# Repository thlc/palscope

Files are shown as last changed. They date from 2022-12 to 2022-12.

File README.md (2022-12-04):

PalScope -- PAL to X-Y-Z Oscilloscope Raster
============================================

About
-----

PalScope is a KiCad version of the very nice schematic made by
[W2AEW](https://www.qsl.net/w2aew/), which converts a PAL signal into 
a 3-channel X-Y-Z raster that oscilloscopes can use to display a raster image.

Components
----------

The board is based around an LM1881 IC that extracts vertical and horizontal
sync pulses from the PAL signal. Those pulses are used to drive capacitors
that produce a 0-9V signal for the X and Y channels.

The Z channel is used to dim parts of the screen using an inverting opamp.
While W2AEW used an AD8032, I had to use an AD844 because I couldn't find
the 8032. This opamp isn't the best, especially since it's current-based.
If you can get hold of a 8032, go this way!

Pictures
--------

Schematic:

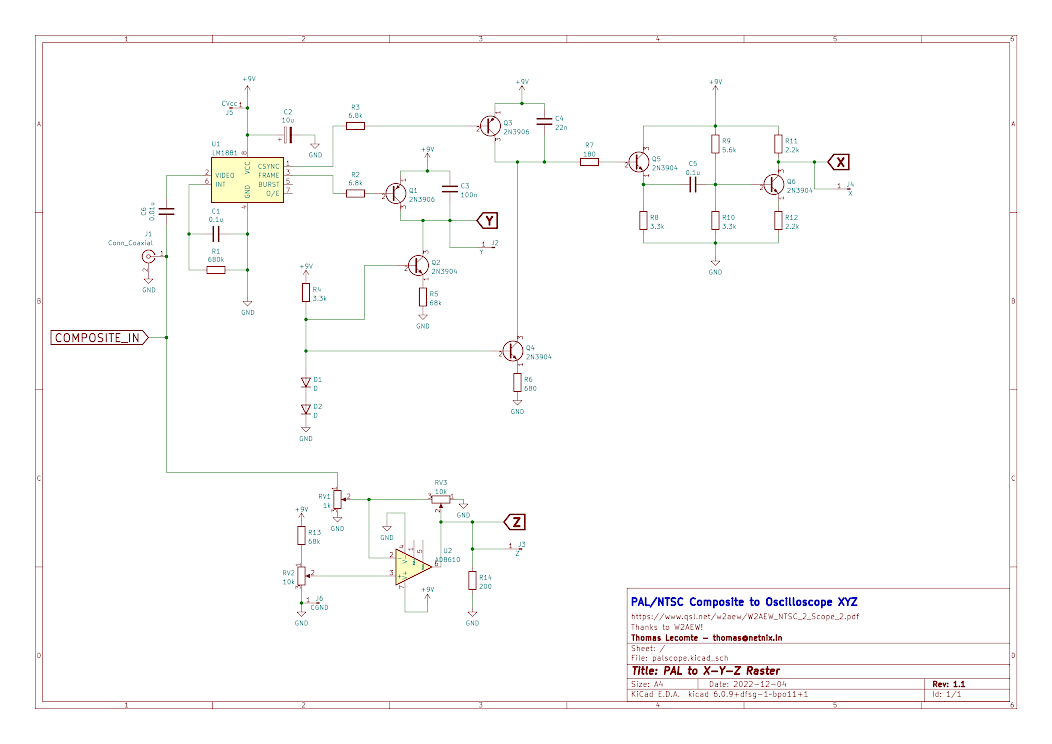
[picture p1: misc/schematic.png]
The Schematic


3-D rendering of the board:

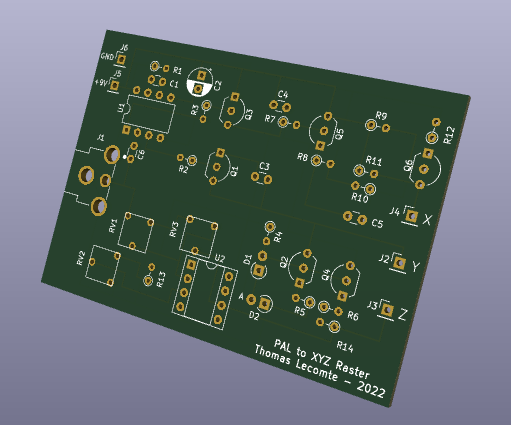
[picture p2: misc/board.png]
3-D Rendering


An early working version of the PCB:

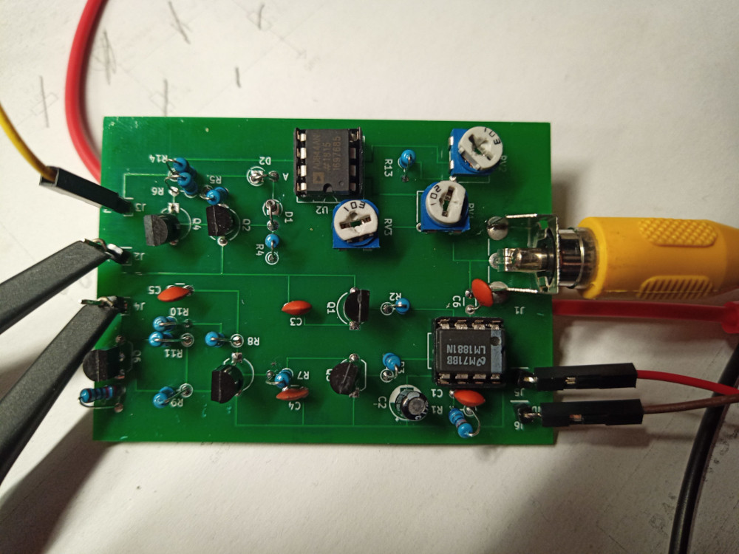
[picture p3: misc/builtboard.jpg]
PCB


My Apple //e running Ultima IV:

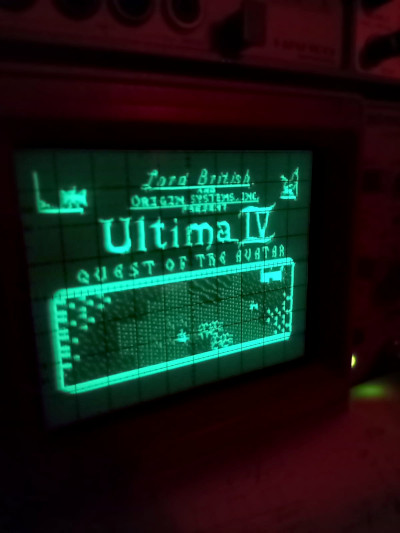
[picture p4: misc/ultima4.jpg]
Apple 2 running Ultima IV


Acknolwedgements
----------------

Thanks to Alan Wolke / W2AEW for publishing this design!
Make sure to check out his YouTube channel at https://www.youtube.com/@w2aew

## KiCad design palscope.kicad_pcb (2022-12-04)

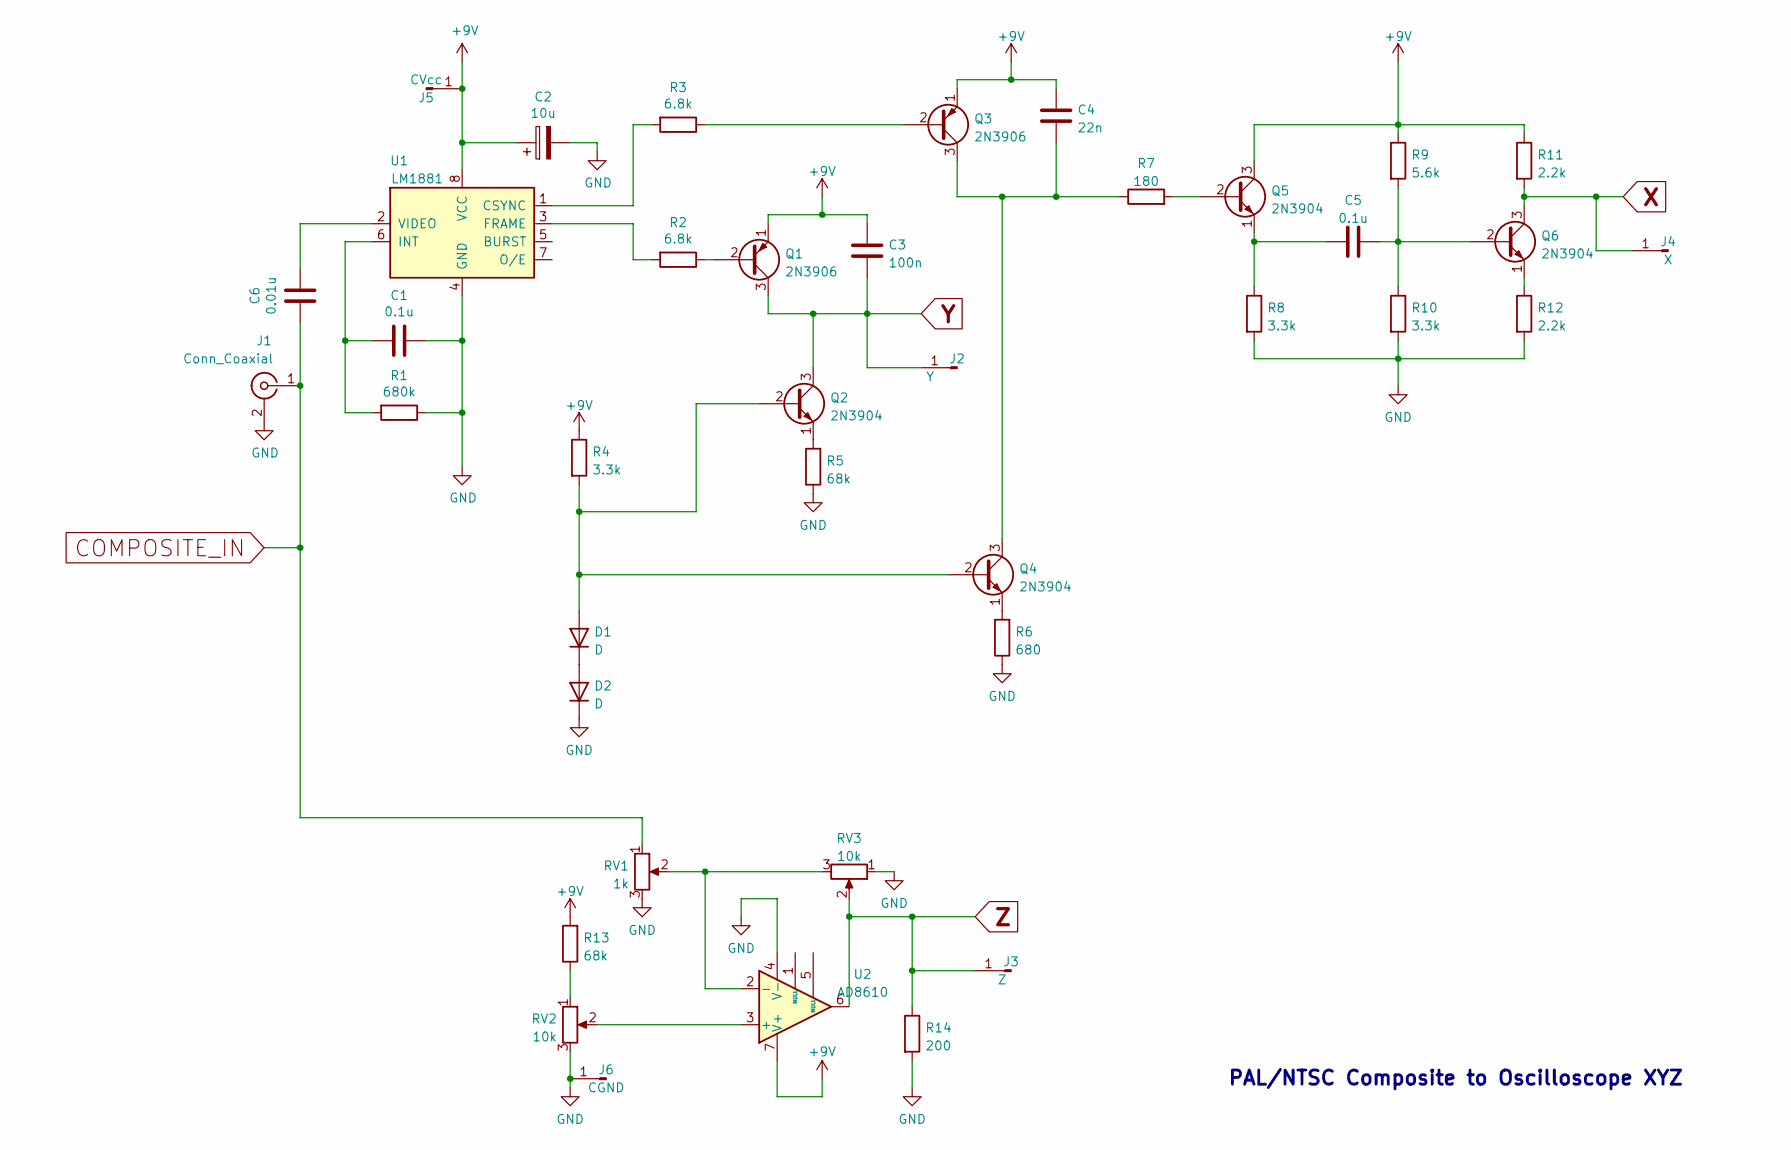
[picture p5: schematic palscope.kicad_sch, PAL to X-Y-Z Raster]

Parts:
C1, C5: 0.1u; C_Disc_D3.0mm_W1.6mm_P2.50mm
C2: 10u; CP_Radial_D5.0mm_P2.50mm
C3: 100n; C_Disc_D3.0mm_W1.6mm_P2.50mm
C4: 22n; C_Disc_D3.0mm_W1.6mm_P2.50mm
C6: 0.01u; C_Disc_D3.0mm_W1.6mm_P2.50mm
D1, D2: D; D_A-405_P2.54mm_Vertical_AnodeUp
J1: Conn_Coaxial; CUI_RCJ-013
J2: Y; PinHeader_1x01_P2.54mm_Vertical
J3: Z; PinHeader_1x01_P2.54mm_Vertical
J4: X; PinHeader_1x01_P2.54mm_Vertical
J5: CVcc; PinHeader_1x01_P2.54mm_Vertical
J6: CGND; PinHeader_1x01_P2.54mm_Vertical
Q1, Q3: 2N3906; TO-92_Inline_Wide
Q2, Q4, Q5, Q6: 2N3904; TO-92_Inline_Wide
R1: 680k; R_Axial_DIN0204_L3.6mm_D1.6mm_P2.54mm_Vertical
R2, R3: 6.8k; R_Axial_DIN0204_L3.6mm_D1.6mm_P2.54mm_Vertical
R4, R8, R10: 3.3k; R_Axial_DIN0204_L3.6mm_D1.6mm_P2.54mm_Vertical
R5, R13: 68k; R_Axial_DIN0204_L3.6mm_D1.6mm_P2.54mm_Vertical
R6: 680; R_Axial_DIN0204_L3.6mm_D1.6mm_P2.54mm_Vertical
R7: 180; R_Axial_DIN0204_L3.6mm_D1.6mm_P2.54mm_Vertical
R9: 5.6k; R_Axial_DIN0204_L3.6mm_D1.6mm_P2.54mm_Vertical
R11, R12: 2.2k; R_Axial_DIN0204_L3.6mm_D1.6mm_P2.54mm_Vertical
R14: 200; R_Axial_DIN0204_L3.6mm_D1.6mm_P2.54mm_Vertical
RV1: 1k; Potentiometer_Bourns_3386F_Vertical_copy
RV2, RV3: 10k; Potentiometer_Bourns_3386F_Vertical_copy
U1: LM1881; DIP-8_W7.62mm
U2: AD8610; DIP-8_W7.62mm_Socket

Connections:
+9V: C2.1, C3.1, C4.1, J5.1, Q1.1 (E), Q3.1 (E), Q5.3 (C), R4.1, R9.1, R11.1, R13.2, U1.8 (VCC), U2.7 (V+)
COMPOSITE_IN: C6.2, J1.1 (In), RV1.1
GND: C1.1, C2.2, D2.1 (K), J1.2 (Ext), J6.1, R1.1, R5.1, R6.1, R8.2, R10.2, R12.2, R14.2, RV1.3, RV2.3, RV3.1, U1.4 (GND), U2.4 (V-)
unnamed: C1.2, R1.2, U1.6 (INT)
unnamed: C4.2, Q3.3 (C), Q4.3 (C), R7.1
unnamed: C5.1, Q5.1 (E), R8.1
unnamed: C5.2, Q6.2 (B), R9.2, R10.1
unnamed: C6.1, U1.2 (VIDEO)
unnamed: D1.1 (K), D2.2 (A)
unnamed: D1.2 (A), Q2.2 (B), Q4.2 (B), R4.2
unnamed: Q1.2 (B), R2.1
unnamed: Q2.1 (E), R5.2
unnamed: Q3.2 (B), R3.1
unnamed: Q4.1 (E), R6.2
unnamed: Q5.2 (B), R7.2
unnamed: Q6.1 (E), R12.1
unnamed: R2.2, U1.3 (FRAME)
unnamed: R3.2, U1.1 (CSYNC)
unnamed: R13.1, RV2.1
unnamed: RV1.2, RV3.3, U2.2 (-)
unnamed: RV2.2, U2.3 (+)
X: J4.1, Q6.3 (C), R11.2
Y: C3.2, J2.1, Q1.3 (C), Q2.3 (C)
Z: J3.1, R14.1, RV3.2, U2.6

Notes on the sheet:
PAL/NTSC Composite to Oscilloscope XYZ

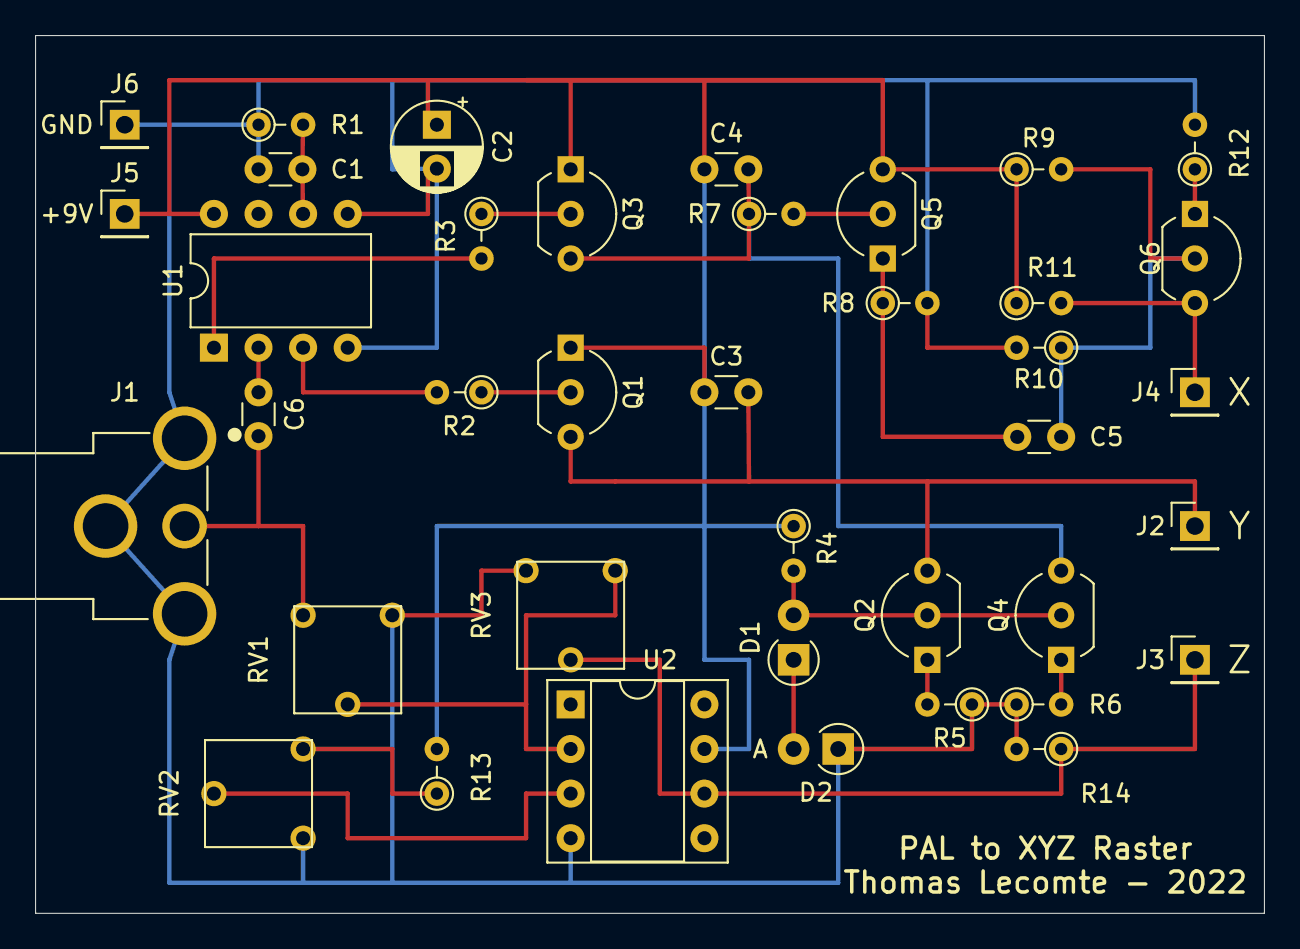
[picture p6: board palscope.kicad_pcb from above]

Board: 2 copper layers, 70.0 x 50.0 mm, 39 parts (0 on the bottom side), 24 nets.

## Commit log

2022-11-13 PALscope KiCad Project
    [palscope.kicad_pcb, palscope.kicad_sch, palscope.sch]
2022-12-04 reworked PCB, removed useless connections, fixed bad C6 capacity
    [palscope.kicad_pcb, palscope.kicad_sch]
